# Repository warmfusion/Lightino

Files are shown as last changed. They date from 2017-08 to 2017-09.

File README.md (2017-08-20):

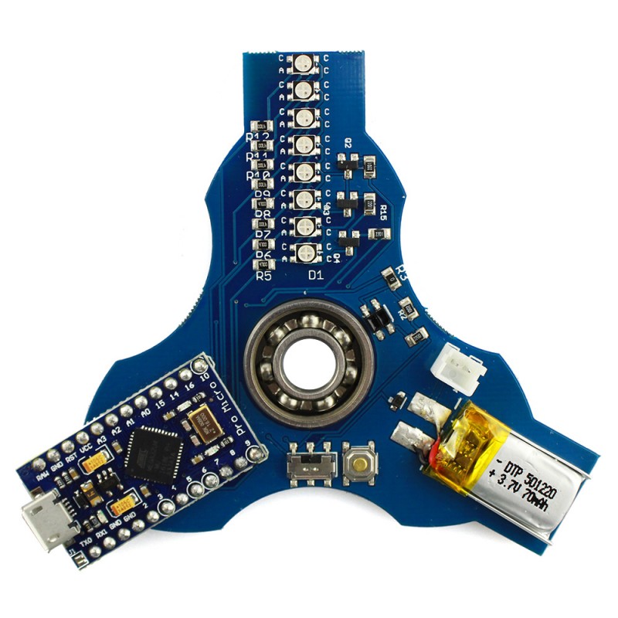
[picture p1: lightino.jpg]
Lightino STEAM Fidget Spinner


**Lightino STEAM Fidget Spinner**

For more details, check out the product page at

http://makerstorage.com/index.php?id_product=29&controller=product

MakerStorage invests time and resources providing this open source design, please support MakerStorage and open-source hardware by purchasing products from MakerStorage!

Designed by MakerStorage LLC.

Creative Commons Attribution, Share-Alike license, check https://creativecommons.org/licenses/by-sa/3.0/ for more information All text above must be included in any redistribution

I am thinking for a while about how to teach young generation coding funnily. We all know it is essential to learn how to code, but it is not so easy. It takes time, and most of the young learners give up and fail at the beginning. You need something interesting to continue and try many times even you fail one after the other. It requires more time and practice than you might expect, so you need a feedback mechanism that motivates you on trying without giving up. It is an absolute truth that Fidget Spinners finds its way into the hearts of young people. I decided to use this popularity and create a fidget spinner with RGB LEDs and Arduino. It was a combination of two things that I love the most.

Our Blog for code sharing: https://lightino.org/

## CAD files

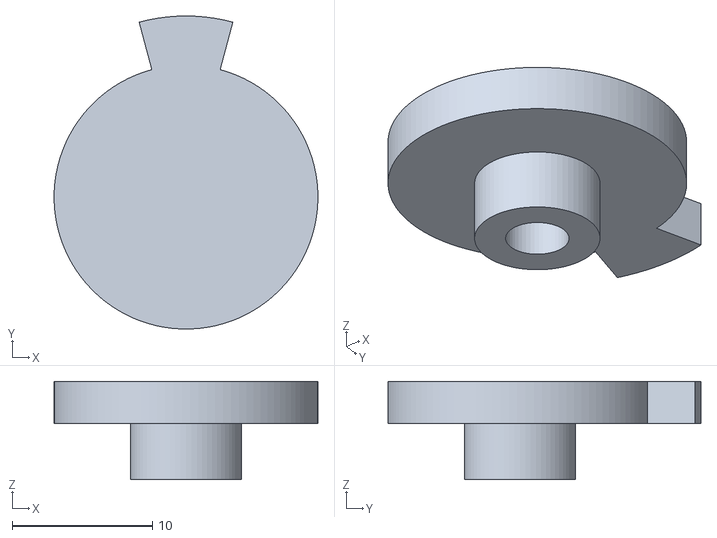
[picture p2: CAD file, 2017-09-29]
tekli.stl
18.8 x 22.3 x 7.00

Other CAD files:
tekli.ipt

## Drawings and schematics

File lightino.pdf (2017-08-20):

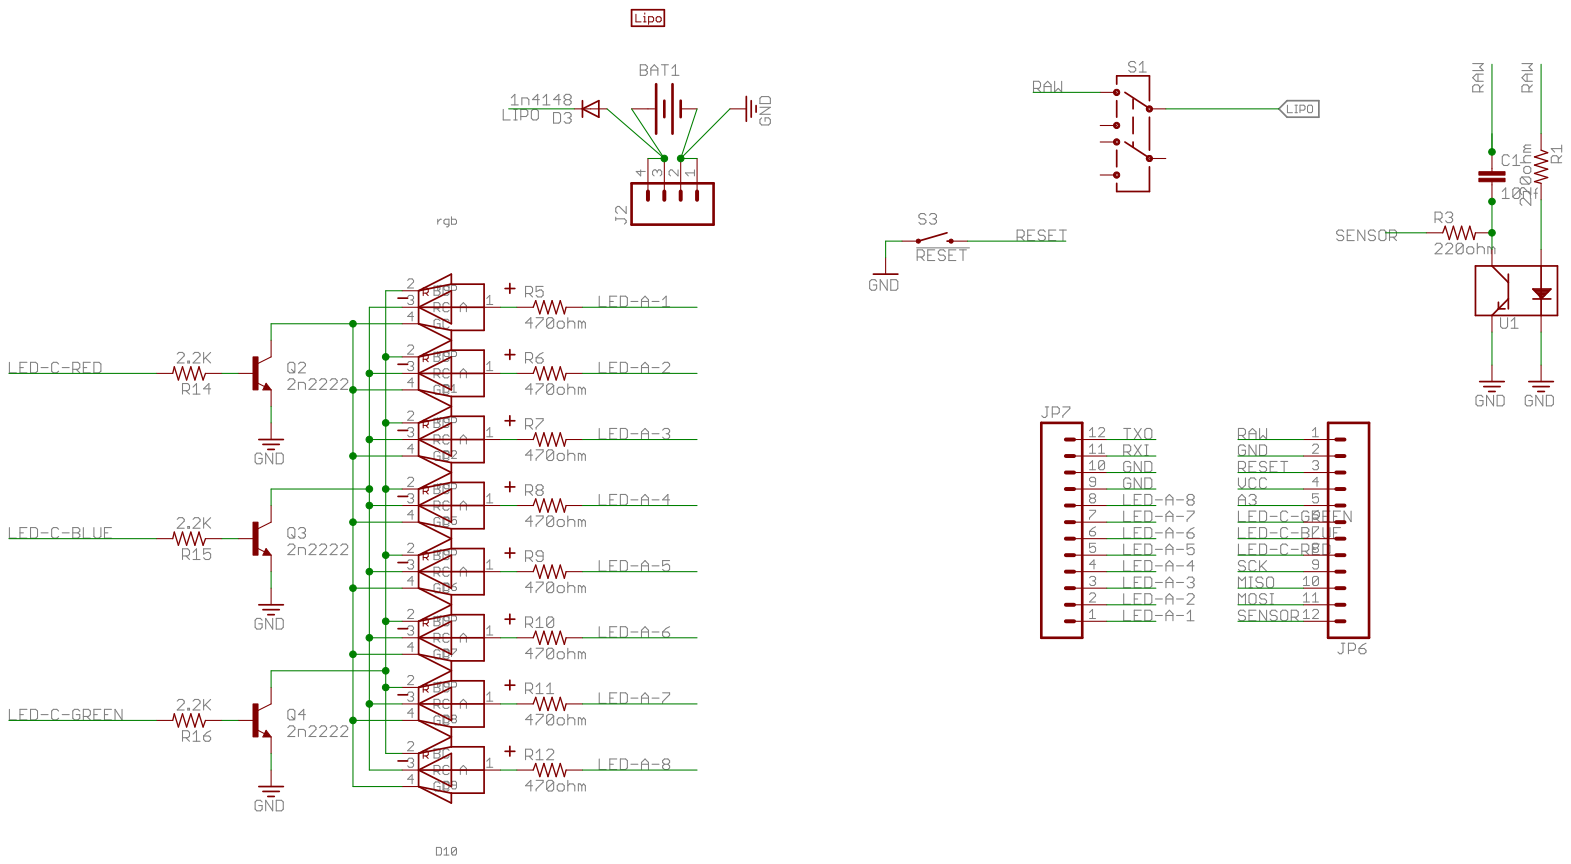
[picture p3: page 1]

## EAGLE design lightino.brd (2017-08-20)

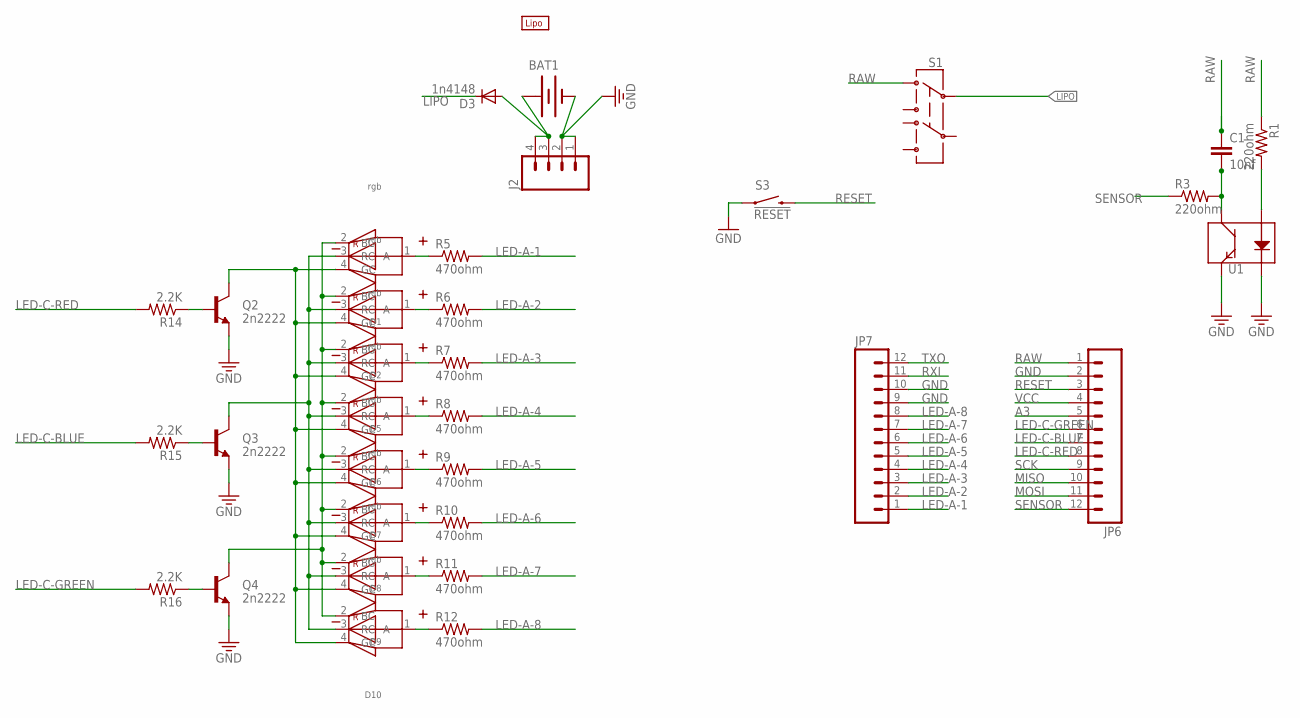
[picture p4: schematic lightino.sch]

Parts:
BAT1: BATTERYLIPO-TABS; LIPO-110-TABS
C1: 10nf; 0805
D1, D2, D5, D6, D7, D8, D9, D10: rgb; 3528-COMMON-ANODE
D3: 1n4148; SOD-323
J2: M041.27MM; 1X04-1.27MM
JP6, JP7: M12PTH; 1X12
Q2, Q3, Q4: 2n2222; SOT23
R1, R3: 220ohm; M0805
R5, R6, R7, R8, R9, R10, R11, R12: 470ohm; M0805
R14, R15, R16: 2.2K; M0805
S1: SWITCH-DPDTAYZ0202; AYZ0202
S3: !RESET; TACTILE_SWITCH_SMD
U1: QRE1113SMD-W; QRE1113-W
U$1: LIPO-OUTLINE100; LIPO-100

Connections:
A3: JP6.5
GND: BAT1.-, J2.1, J2.2, JP6.2, JP7.9, JP7.10, Q2.2 (E), Q3.2 (E), Q4.2 (E), S3.1, U1.2 (K), U1.4 (E)
LED-A-1: JP7.1, R5.2
LED-A-2: JP7.2, R6.2
LED-A-3: JP7.3, R7.2
LED-A-4: JP7.4, R8.2
LED-A-5: JP7.5, R9.2
LED-A-6: JP7.6, R10.2
LED-A-7: JP7.7, R11.2
LED-A-8: JP7.8, R12.2
LED-C-BLUE: JP6.7, R15.2
LED-C-GREEN: JP6.6, R16.2
LED-C-RED: JP6.8, R14.2
LIPO: D3.1 (C), S1.2
MISO: JP6.10
MOSI: JP6.11
unnamed: BAT1.+, D3.2 (A), J2.3, J2.4
unnamed: R1.2, U1.1 (A)
unnamed: D2.1 (A), R6.1
unnamed: D1.1 (A), R5.1
unnamed: D10.1 (A), R12.1
unnamed: D9.1 (A), R11.1
unnamed: D8.1 (A), R10.1
unnamed: D7.1 (A), R9.1
unnamed: D6.1 (A), R8.1
unnamed: D5.1 (A), R7.1
unnamed: D1.2 (BC), D2.2 (BC), D5.2 (BC), D6.2 (BC), D7.2 (BC), D8.2 (BC), D9.2 (BC), D10.2 (BC), Q4.3 (C)
unnamed: D1.3 (RC), D2.3 (RC), D5.3 (RC), D6.3 (RC), D7.3 (RC), D8.3 (RC), D9.3 (RC), D10.3 (RC), Q3.3 (C)
unnamed: D1.4 (GC), D2.4 (GC), D5.4 (GC), D6.4 (GC), D7.4 (GC), D8.4 (GC), D9.4 (GC), D10.4 (GC), Q2.3 (C)
unnamed: Q2.1 (B), R14.1
unnamed: Q3.1 (B), R15.1
unnamed: Q4.1 (B), R16.1
RAW: C1.1, JP6.1, R1.1, S1.1
RESET: JP6.3, S3.3 (2)
RXI: JP7.11
SCK: JP6.9
SENSOR: JP6.12, R3.1
TXO: JP7.12
VCC: JP6.4
XX: C1.2, R3.2, U1.3 (C)

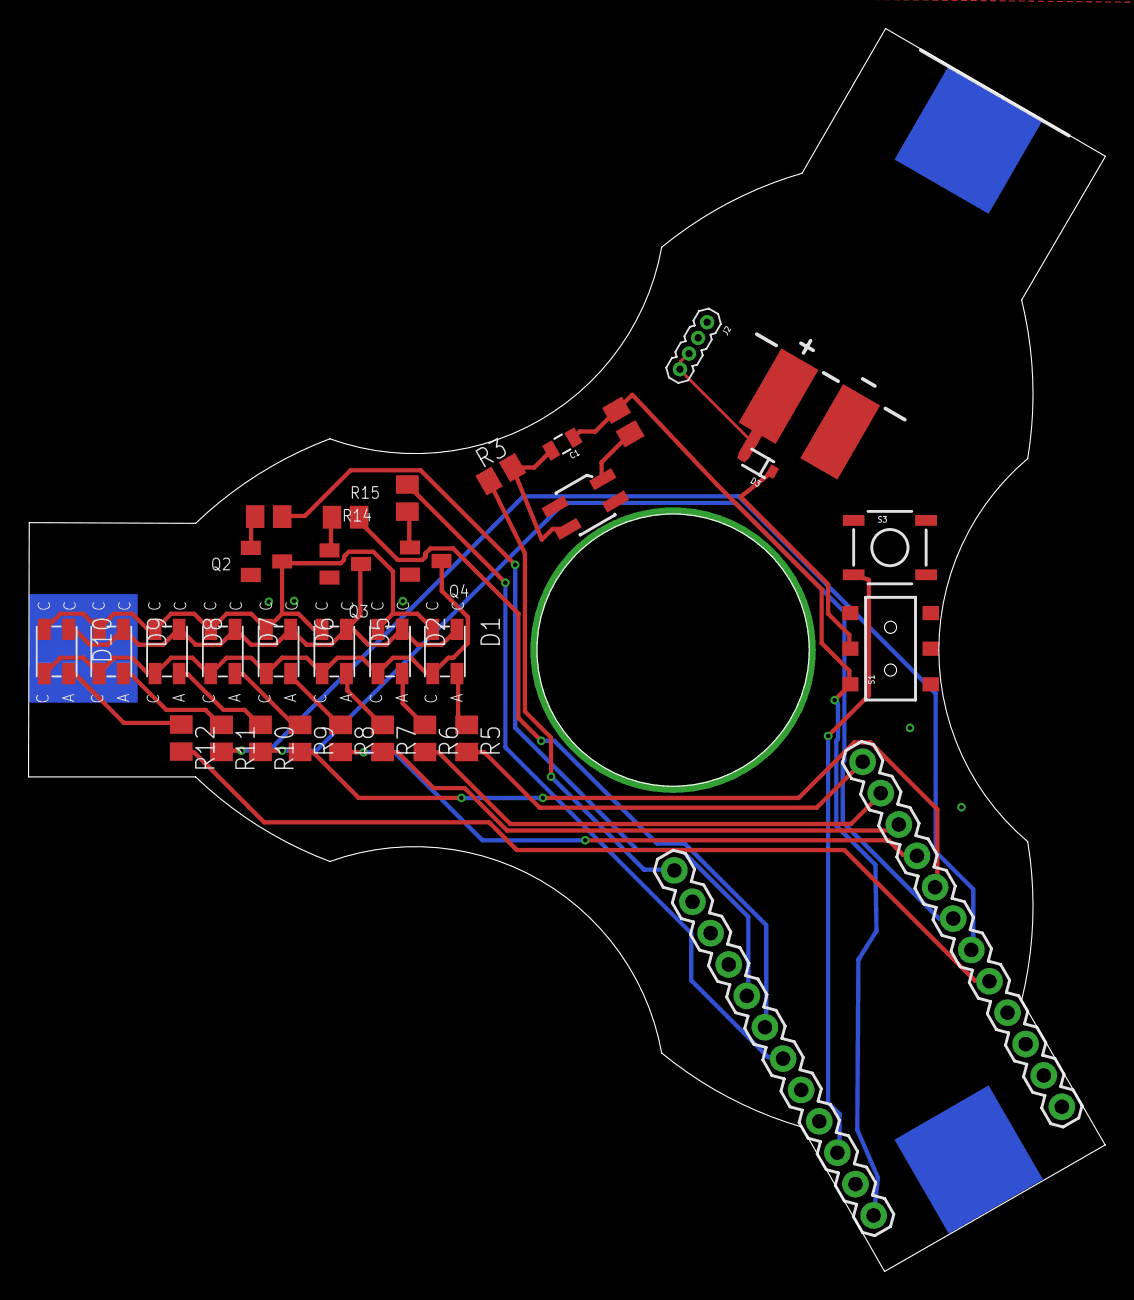
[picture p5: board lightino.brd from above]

Board: 2 copper layers, 75.5 x 87.2 mm, 34 parts (0 on the bottom side), 33 nets.

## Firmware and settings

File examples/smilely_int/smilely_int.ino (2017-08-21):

//***************************************************************
//Lightino is an open source project develop by MakerStorage LLC.
//It is a STEM & EdTech. fidget spinner for students to learn code.
//Please contrubute and suport this project at lightino.org
// e-mail:ne@makerstorage.com
//***************************************************************
//delay functions and graphics taken from Ken (MakerBox)
//***************************************************************





#define BLUE  A1
#define RED   A0
#define GREEN A2
#define LED1 9
#define LED2 8
#define LED3 7
#define LED4 6
#define LED5 5
#define LED6 4
#define LED7 3
#define LED8 2
#define SENSOR A10

byte data[] = { 
  B00000100,
  B00000100,
  B00000010,
  B00000010,
  B00000010,
  B00000001,
  B00000001,
  B00000001,
  B00000001,
  B00000001,
  B00000010,
  B00000010,
  B00000100,
  B00001000,
  B00010000,
  B00100000,
  B01000000,
  B10000000,
  B10000000,
  B01000000,
  B00100000,
  B00010000,
  B00001000,
  B00000100,
  B00000010,
  B00000001,
  B00000001,
  B00000001,
  B00000001,
  B00000001,
  B00000010,
  B00000010,
  B00000010,
  B00000100,
  B00000100,
  B00000100,
  B00000100,
  B00001000,
  B00001000,
  B00001000,
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
  
  
};

byte data1[] = { 
  B00000001,
  B00000001,
  B00000001,
  B00000001,
  B00000001,
  B00000001,
  B00100001,
  B01010001,
  B01001001,
  B01001001,
  B01010001,
  B00100001,
  B00000001,
  B00000001,
  B00000001,
  B00000001,
  B00000001,
  B00000001,
  B00000001,
  B00000001,
  B00000001,
  B00000001,
  B00000001,
  B00000001,
  B00100001,
  B01010001,
  B01001001,
  B01001001,
  B01010001,
  B00100001,
  B00000001,
  B00000001,
  B00000001,
  B00000001,
  B00000001,
  B00000001,
  B00000001,
  B00000001,
  B00000001,
  B00000001,
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
  
  
};


uint8_t led_anodes[] = {LED8, LED7, LED6, LED5, LED4, LED3, LED2, LED1};
uint8_t led_cathodes[] = {GREEN, RED, BLUE};
int color = 0; //color index 0 to 2
boolean flag=true;

unsigned long long lastTimeUs;                // time (us) magnet sensed
unsigned long long revTimeUs;                 // time (us) of last full rotation
unsigned long long dwellTimeUs;               // time (us) between LED changes (based on rotation speed)



void setup() {

 // Interupt setting
   PCMSK0 = bit (PCINT6); //Use PCINT6 = PB6 pin 30.
   PCICR |= (1<<PCIE0);   //Enable Pin change interrupt
   sei();


 // Serial.begin(9600);
 //  while (!Serial) ;
  
  TXLED0;// on board leds off
  RXLED0;
  
  pinMode(RED, OUTPUT); 
  pinMode(BLUE, OUTPUT); 
  pinMode(GREEN, OUTPUT); 
  
  pinMode(LED8, OUTPUT);
  pinMode(LED7, OUTPUT);
  pinMode(LED6, OUTPUT);
  pinMode(LED5, OUTPUT);
  pinMode(LED4, OUTPUT);
  pinMode(LED3, OUTPUT);
  pinMode(LED2, OUTPUT);
  pinMode(LED1, OUTPUT);

  pinMode(SENSOR, INPUT);
  digitalWrite(SENSOR,HIGH); 
  

   // default off
  digitalWrite(RED, LOW);
  digitalWrite(BLUE, LOW);;
  digitalWrite(GREEN, LOW); 
  
  digitalWrite(LED1, LOW);
  digitalWrite(LED2, LOW);
  digitalWrite(LED3, LOW);
  digitalWrite(LED4, LOW);
  digitalWrite(LED5, LOW);
  digitalWrite(LED6, LOW);
  digitalWrite(LED7, LOW);
  digitalWrite(LED1, LOW);

  lastTimeUs = micros();
}

void loop() {
  unsigned long long curTimeUs;
//  TXLED0;  //TX LED OFFF
 // RXLED0;  //TX LED OFFF






    
//ADC_TIME_13;  // 13us conversion time
//int QRE_Value = analogRead(SENSOR);

//if (!(QRE_Value > 900)) { //sensor trigered
//  flag=true;
  

//}
  

if (flag){  
flag=false;

  curTimeUs = micros();
  revTimeUs =  curTimeUs - lastTimeUs;
  lastTimeUs = curTimeUs; 
  setColor (0);  
  for(int k=0; k<72; k++){
        if (flag){
          break;
        }
    byte oneByte = data[k];
    
    for(int LED=0; LED<8; LED++){
      // color++; //increment color index
      // if (color>=3) color =0; //prevent grow up
       digitalWrite(led_anodes[LED], bitRead(oneByte,LED)); 
       if (flag){
          break;
        }
           
     }  
   
   
   dwellTimeUs = (revTimeUs * 4ul / 360ul);  //making 4ul not works

  
  
 // dwellTimeUs = (revTimeUs*0.012); 
 // dwellTimeUs = round (revTimeUs / 72);
  dwellDelay();
   //   delayMicroseconds(dwellTimeUs);
  

  }

}
 
else {
   // AllLedsOff();
}




}//loop

void AllLedsOff(){

   for(int LED=0; LED<8; LED++){
       digitalWrite(led_anodes[LED], 0); 
       setColor (-1);       
     }  

}


void setColor (int color){

switch (color) {
    case 0:    //red
      digitalWrite(led_cathodes[0], LOW);
      digitalWrite(led_cathodes[1], LOW);
      digitalWrite(led_cathodes[2], HIGH);
      break;
      
    case 1:    //green
      digitalWrite(led_cathodes[0], LOW);
      digitalWrite(led_cathodes[1], HIGH);
      digitalWrite(led_cathodes[2], LOW);
      break;
      
    case 2:    //blue
      digitalWrite(led_cathodes[0], HIGH);
      digitalWrite(led_cathodes[1], LOW);
      digitalWrite(led_cathodes[2], LOW);
      break;

     default:
        // turn all the LEDs off:  
      digitalWrite(led_cathodes[0], LOW);
      digitalWrite(led_cathodes[1], LOW);
      digitalWrite(led_cathodes[2], LOW);
     
  }

  
}

void dwellDelay(){ // avoid glitch on first rotation having erronious value 
  if (dwellTimeUs > 2000){
    dwellTimeUs = 2000;
  }
  if (dwellTimeUs < 100){
    dwellTimeUs = 100;
  }  
  delayMicroseconds(dwellTimeUs);
}

ISR(PCINT0_vect){  // Magnet sensed
  if (!digitalRead(SENSOR)){
    flag = true;             // Increment volatile variables
   // revolutions += 1;
  }
}

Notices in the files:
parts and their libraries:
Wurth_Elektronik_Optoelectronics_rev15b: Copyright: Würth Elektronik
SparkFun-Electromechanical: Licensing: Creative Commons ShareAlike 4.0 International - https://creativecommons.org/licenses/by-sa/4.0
